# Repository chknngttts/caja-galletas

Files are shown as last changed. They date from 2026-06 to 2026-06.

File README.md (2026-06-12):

# caja-galletas

> *Caja de ruido en proceso*
>
> *Todas las versiones de KiCad están en sus carpetas propias*

-------------------

- ### Ideas y specs

> *La idea es tener esta PCB en una caja de galletas*
> 
> *La placa en sí ya tiene efectos integrados como reverb y un Muff Fuzz*
> 
> *La caja se conecta a un parlante o pc con Jack 3.5mm*
> 
> *Y como alimentación también cuenta con un Jack 3.5mm*
> 

  - Dentro de la caja hay:
    - Regulador de voltaje **``(9V -----> 5V)``**
      - VBUS
    - Reverb **``(PT2399)``**
      - *Switch para tener feedback*
    - Pre-Amp / Amp **``(TL072)``**
    - Muff Fuzz **``(2N5088)``**

-  ## **v2**

- ### esquematico v2

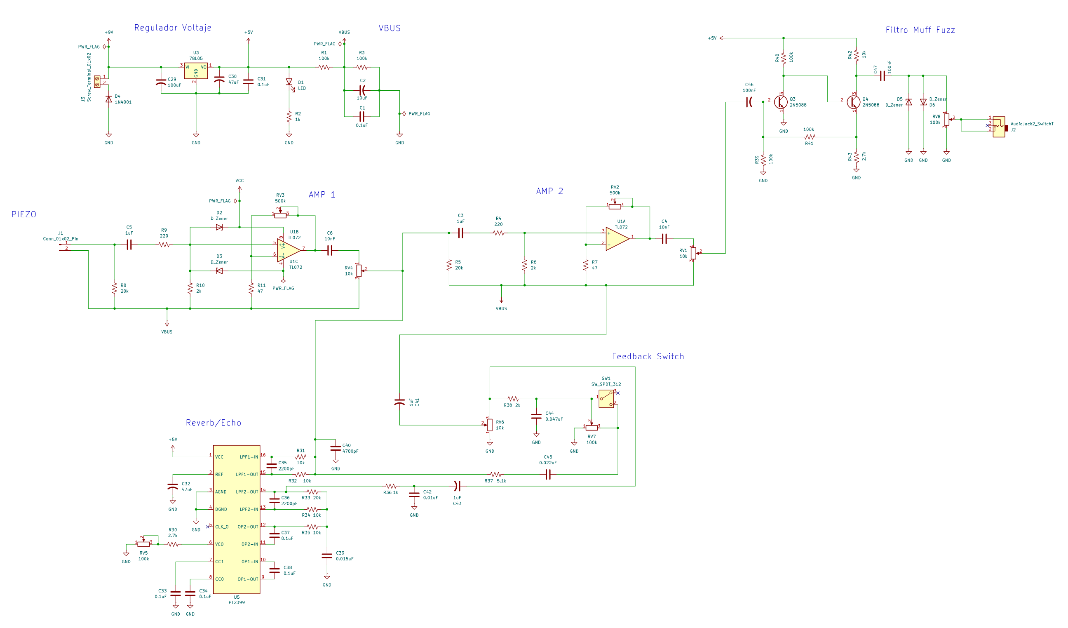
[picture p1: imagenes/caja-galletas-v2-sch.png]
v2 esquematico
-  

-  El esqumatico del PT2399 es el "Boy in Well" con un mod de DIY Guitar Pedals:
    - https://youtu.be/9sHnaUfTWug?si=lqVHKw3zSinBoRW7&t=106 (1:46 - 4:46)
    - Muestra que cortando la conexión de un potenciómetro (RV7) con un switch y bajando el valor de una resistencia (R37), permite que la señal no se filtre (y no pierda info) para que llegue de vuelta al PT2399 haciendo repeats infinitos
      - https://www.diyguitarpedals.com.au/shop/boms/Boy%20in%20Well.pdf (Esquematico original sin switch) (Pagina 30)
    - En KiCad al hacer el ERC no me arroja errores
      - Solo 2 avisos de simbolos que modifiqué para hacer más facil el esquematico
      - En la PBC tampoco me muestra errores de conexión
        - Si quiero cambiar el tamaño y orden de la placa
          - Más rectangular y ahorrar espacio
         
-------------------
- Pre-Amp:         
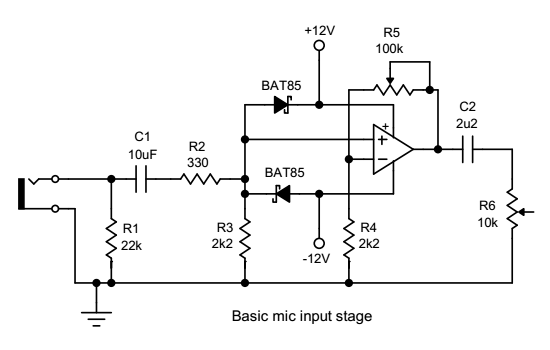
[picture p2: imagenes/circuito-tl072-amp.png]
pre-amp
  - 
  - El Amp que tomé de referencia, es el mismo que el de [maincra](https://github.com/disenoUDP/dis8644-2026-1-procesos-2/tree/main/00-proyecto-02/grupo-01)
    - Con los cambios para hacer más sensible el piezo (R4 y R5)
    - Eso sí, ahora usando ambos OP-Amps

- Muff Fuzz:
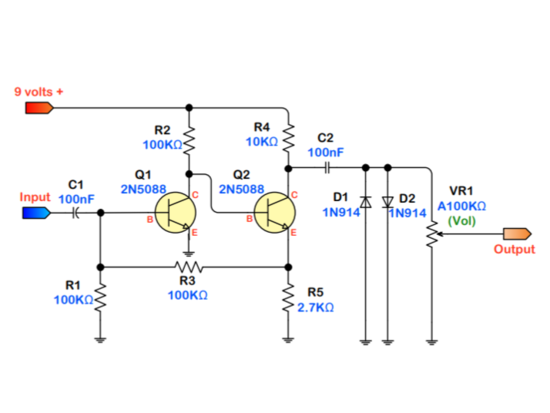
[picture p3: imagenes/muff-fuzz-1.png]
muff-fuzz
  - 
  - El efecto "Muff Fuzz" lo saqué de esta pagina:
    - https://beavisaudio.com/beavisboard/projects/bbp_MuffFuzz.pdf
 
-------------------

- ### pcb v2

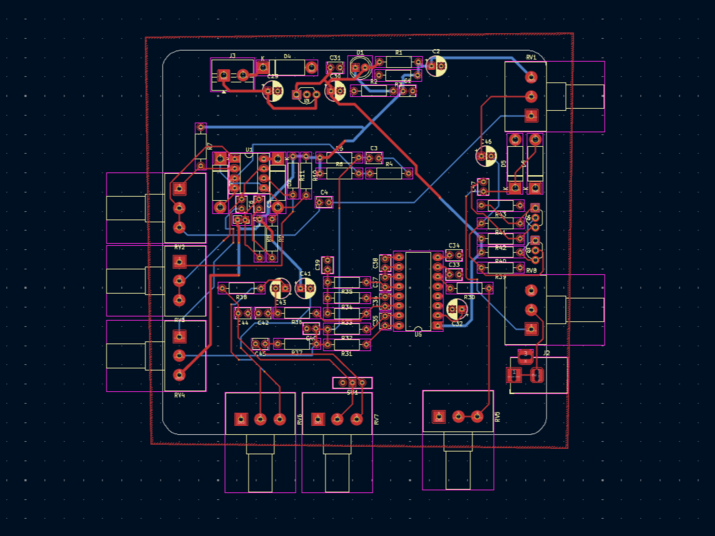
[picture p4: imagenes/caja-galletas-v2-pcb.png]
v2 pcb 2d
- 
  - Tengo que arreglar las vías *(?)*
    - Sin querer use el tamaño predeterminado, no se si eso vaya a ser un problema
  - La huella de los 2N5088 y 78L05 tienen uno externo a la biblioteca de KiCad
    - Los cambié por uno de la biblioteca default en el v3
      - Además de corregir un alivio termico que no nombraban en los errores pero si era preocupante
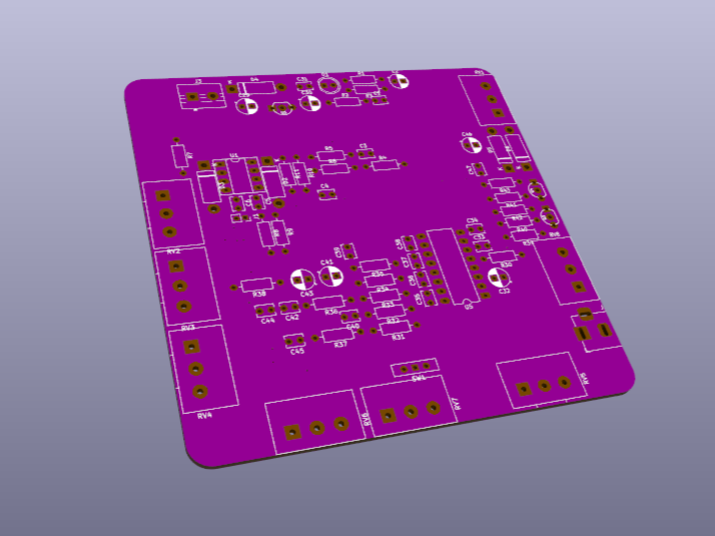
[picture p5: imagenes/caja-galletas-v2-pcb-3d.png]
v2 pcb 3d
- 
  - Hay espacio vacío que me permite re-ordenar los componentes y achicar el tamaño de la PCB
 
-------------------
 
- #### *v3 fueron arreglos minimos de huellas*

-------------------

- ## **v4**

- ### esquematico v4
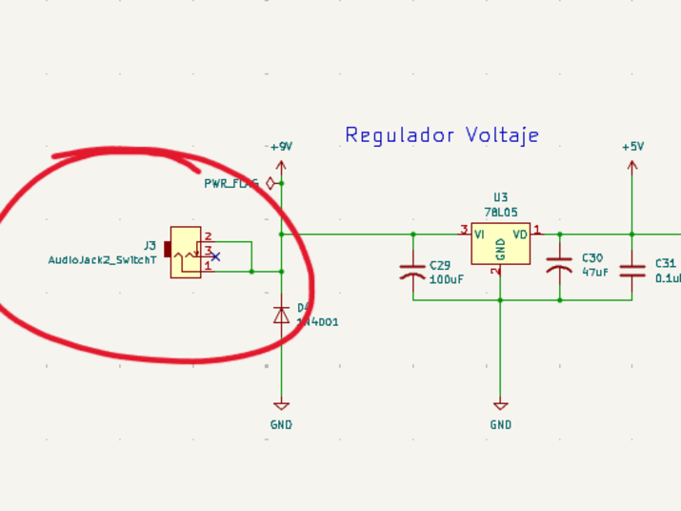
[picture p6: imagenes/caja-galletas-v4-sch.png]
v4 esquematico
  - 
    - igual que v2 pero con Jack 3.5mm a cambio del Terminal Block
 
-------------------
 
- ### pcb v4

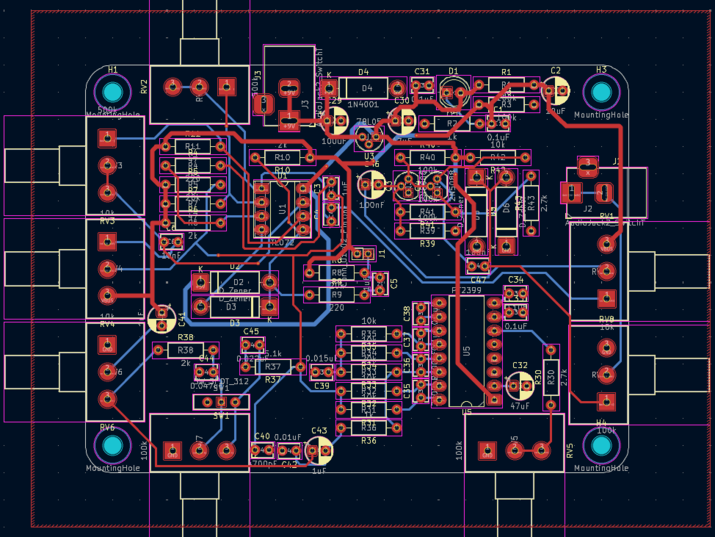
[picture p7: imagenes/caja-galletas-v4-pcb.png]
v4 pcb 2d
- 
  - Cambié las vías al tamaño que nos recomendaros en taller
    - Optimicé la posición de los componentes para usar el espacio vacío
  - Añadí Mounting Holes M3
  - Al ver los errores solo mostraba problemas de la serigrafía
    - Nada con alivios termicos
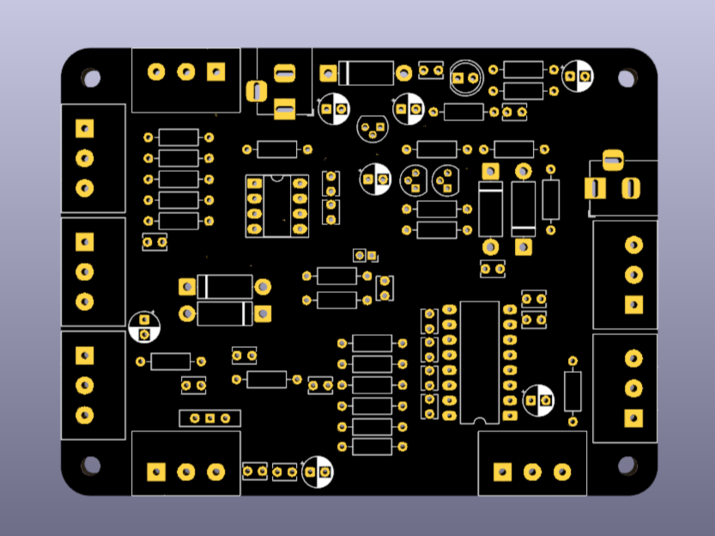
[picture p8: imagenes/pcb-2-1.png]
- 
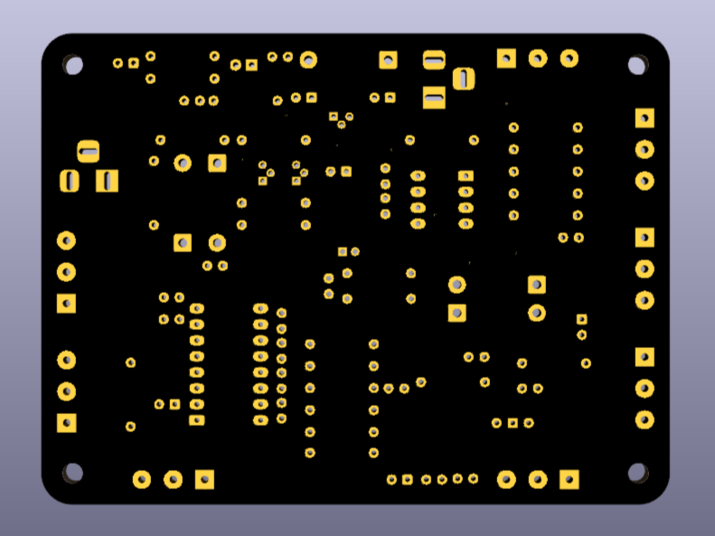
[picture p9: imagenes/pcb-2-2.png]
- 
  - Prefiero el color negro a rosado/morado

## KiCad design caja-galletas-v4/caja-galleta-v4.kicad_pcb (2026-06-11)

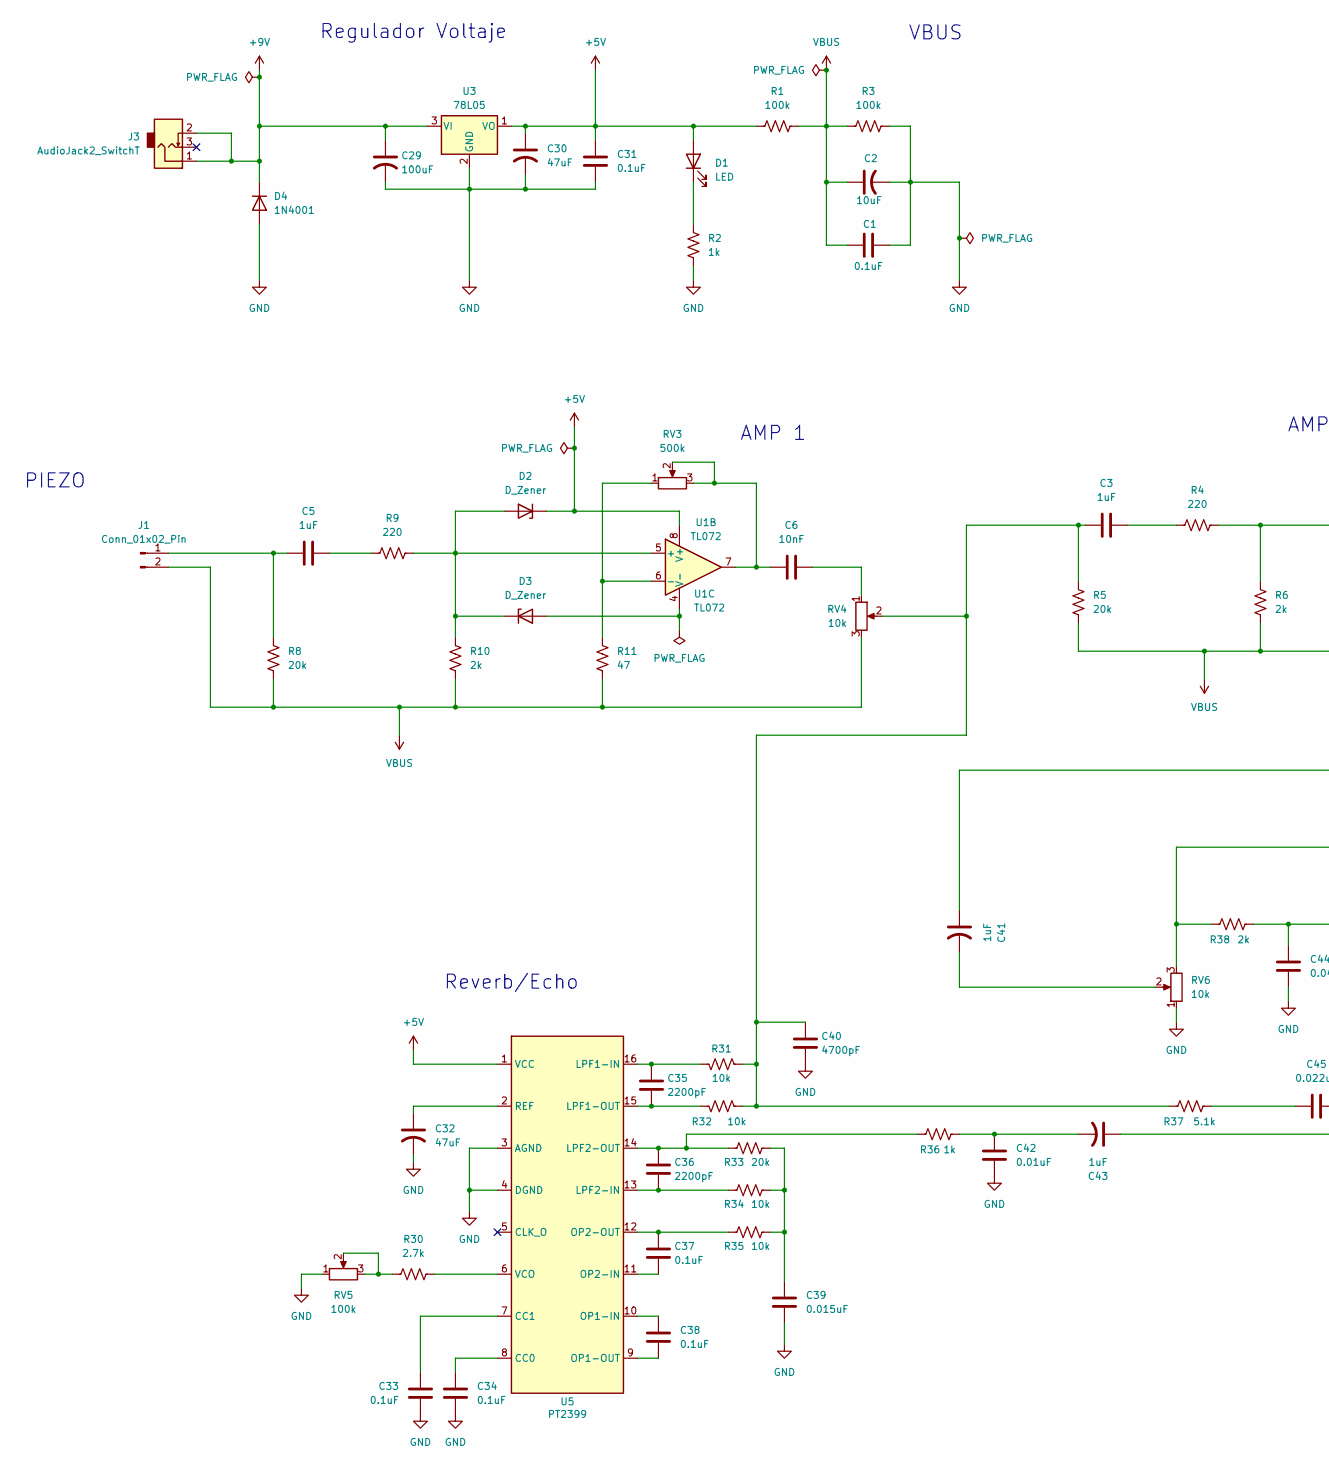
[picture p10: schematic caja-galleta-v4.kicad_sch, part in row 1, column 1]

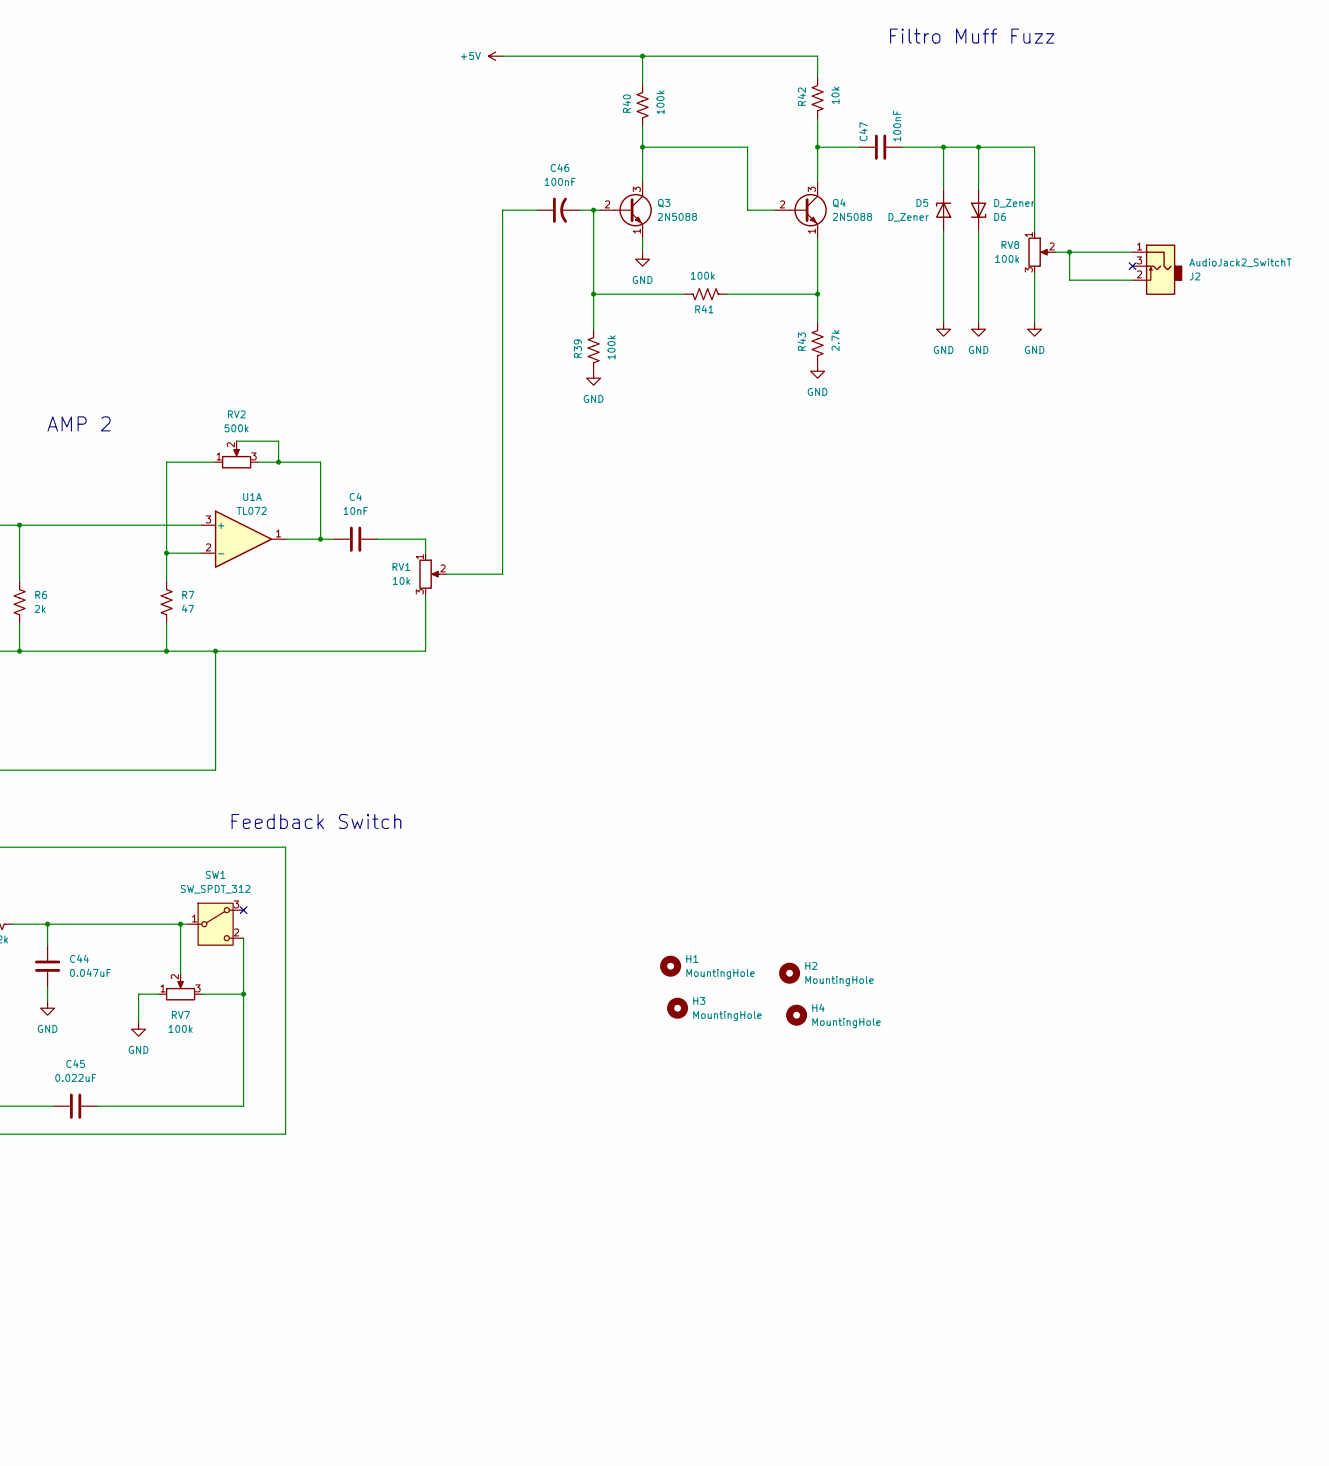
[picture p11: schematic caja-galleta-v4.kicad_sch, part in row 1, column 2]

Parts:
C1, C31, C33, C34, C37, C38: 0.1uF; C_Disc_D3.8mm_W2.6mm_P2.50mm
C2: 10uF; CP_Radial_D5.0mm_P2.50mm
C3, C5: 1uF; C_Disc_D3.8mm_W2.6mm_P2.50mm
C4, C6: 10nF; C_Disc_D3.8mm_W2.6mm_P2.50mm
C29: 100uF; CP_Radial_D5.0mm_P2.50mm
C30, C32: 47uF; CP_Radial_D5.0mm_P2.50mm
C35, C36: 2200pF; C_Disc_D3.8mm_W2.6mm_P2.50mm
C39: 0.015uF; C_Disc_D3.8mm_W2.6mm_P2.50mm
C40: 4700pF; C_Disc_D3.8mm_W2.6mm_P2.50mm
C41, C43: 1uF; CP_Radial_D5.0mm_P2.50mm
C42: 0.01uF; C_Disc_D3.8mm_W2.6mm_P2.50mm
C44: 0.047uF; C_Disc_D3.8mm_W2.6mm_P2.50mm
C45: 0.022uF; C_Disc_D3.8mm_W2.6mm_P2.50mm
C46: 100nF; CP_Radial_D5.0mm_P2.50mm
C47: 100nF; C_Disc_D3.8mm_W2.6mm_P2.50mm
D1: LED; LED_D5.0mm
D2, D3, D5, D6: D_Zener; D_5W_P12.70mm_Horizontal
D4: 1N4001; D_5W_P12.70mm_Horizontal
H1, H2, H3, H4: MountingHole; MountingHole_3.2mm_M3
J1: Conn_01x02_Pin; PinSocket_1x02_P2.00mm_Vertical
J2, J3: AudioJack2_SwitchT; BarrelJack_Horizontal
Q3, Q4: 2N5088; TO-92
R1, R3, R39, R40, R41: 100k; R_Axial_DIN0207_L6.3mm_D2.5mm_P10.16mm_Horizontal
R2, R36: 1k; R_Axial_DIN0207_L6.3mm_D2.5mm_P10.16mm_Horizontal
R4, R9: 220; R_Axial_DIN0207_L6.3mm_D2.5mm_P10.16mm_Horizontal
R5, R8, R33: 20k; R_Axial_DIN0207_L6.3mm_D2.5mm_P10.16mm_Horizontal
R6, R10, R38: 2k; R_Axial_DIN0207_L6.3mm_D2.5mm_P10.16mm_Horizontal
R7, R11: 47; R_Axial_DIN0207_L6.3mm_D2.5mm_P10.16mm_Horizontal
R30, R43: 2.7k; R_Axial_DIN0207_L6.3mm_D2.5mm_P10.16mm_Horizontal
R31, R32, R34, R35, R42: 10k; R_Axial_DIN0207_L6.3mm_D2.5mm_P10.16mm_Horizontal
R37: 5.1k; R_Axial_DIN0207_L6.3mm_D2.5mm_P10.16mm_Horizontal
RV1, RV4, RV6: 10k; Potentiometer_Alps_RK163_Single_Horizontal
RV2, RV3: 500k; Potentiometer_Alps_RK163_Single_Horizontal
RV5, RV7, RV8: 100k; Potentiometer_Alps_RK163_Single_Horizontal
SW1: SW_SPDT_312; SW_Slide-03_Wuerth-WS-SLTV_10x2.5x6.4_P2.54mm
U1: TL072; DIP-8_W7.62mm_Socket_LongPads
U3: 78L05; TO-92
U5: PT2399; DIP-16_W10.16mm_LongPads

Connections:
+5V: C30.1, C31.1, D1.2 (A), D2.1 (K), R1.1, R40.2, R42.2, U1.8 (V+), U3.1 (VO), U5.1 (VCC)
+9V: C29.1, D4.1 (K), J3.1, J3.2, U3.3 (VI)
GND: C1.2, C2.2, C29.2, C30.2, C31.2, C32.2, C33.2, C34.2, C39.2, C40.2, C42.2, C44.1, D4.2 (A), D5.2 (A), D6.1 (K), Q3.1 (E), R2.1, R3.2, R39.1, R43.1, RV5.1, RV6.1, RV7.1, RV8.3, U3.2 (GND), U5.3 (AGND), U5.4 (DGND)
unnamed: C3.1, C40.1, R5.2, R31.2, R32.2, R37.1, RV4.2
unnamed: C3.2, R4.2
unnamed: C4.1, RV2.2, RV2.3, U1.1
unnamed: C4.2, RV1.1
unnamed: C5.2, R9.2
unnamed: C6.1, RV3.2, RV3.3, U1.7
unnamed: C6.2, RV4.1
unnamed: C39.1, R33.2, R34.2, R35.2
unnamed: C41.2, RV6.2
unnamed: C42.1, C43.2, R36.2
unnamed: C43.1, R38.1, RV6.3
unnamed: C45.1, R37.2
unnamed: C46.1, RV1.2
unnamed: D1.1 (K), R2.2
unnamed: D2.2 (A), D3.1 (K), R9.1, R10.2, U1.5 (+)
unnamed: D3.2 (A), U1.4 (V-)
unnamed: C47.1, D5.1 (K), D6.2 (A), RV8.1
unnamed: C5.1, J1.1, R8.2
unnamed: J2.1, J2.2, RV8.2
unnamed: C46.2, Q3.2 (B), R39.2, R41.2
unnamed: Q3.3 (C), Q4.2 (B), R40.1
unnamed: C47.2, Q4.3 (C), R42.1
unnamed: Q4.1 (E), R41.1, R43.2
unnamed: R30.1, RV5.2, RV5.3
unnamed: C44.2, R38.2, RV7.2, SW1.1 (B)
unnamed: C45.2, RV7.3, SW1.2 (C)
unnamed: R4.1, R6.2, U1.3 (+)
unnamed: R7.2, RV2.1, U1.2 (-)
unnamed: R11.2, RV3.1, U1.6 (-)
unnamed: C34.1, U5.8 (CC0)
unnamed: C33.1, U5.7 (CC1)
unnamed: C35.1, R31.1, U5.16 (LPF1-IN)
unnamed: C35.2, R32.1, U5.15 (LPF1-OUT)
unnamed: C36.2, R34.1, U5.13 (LPF2-IN)
unnamed: C36.1, R33.1, R36.1, U5.14 (LPF2-OUT)
unnamed: C38.1, U5.10 (OP1-IN)
unnamed: C38.2, U5.9 (OP1-OUT)
unnamed: C37.2, U5.11 (OP2-IN)
unnamed: C37.1, R35.1, U5.12 (OP2-OUT)
unnamed: C32.1, U5.2 (REF)
unnamed: R30.2, U5.6 (VCO)
VBUS: C1.1, C2.1, C41.1, J1.2, R1.2, R3.1, R5.1, R6.1, R7.1, R8.1, R10.1, R11.1, RV1.3, RV4.3

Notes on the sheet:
AMP 1
Regulador Voltaje
Filtro Muff Fuzz
Feedback Switch
Reverb/Echo
AMP 2
PIEZO
VBUS

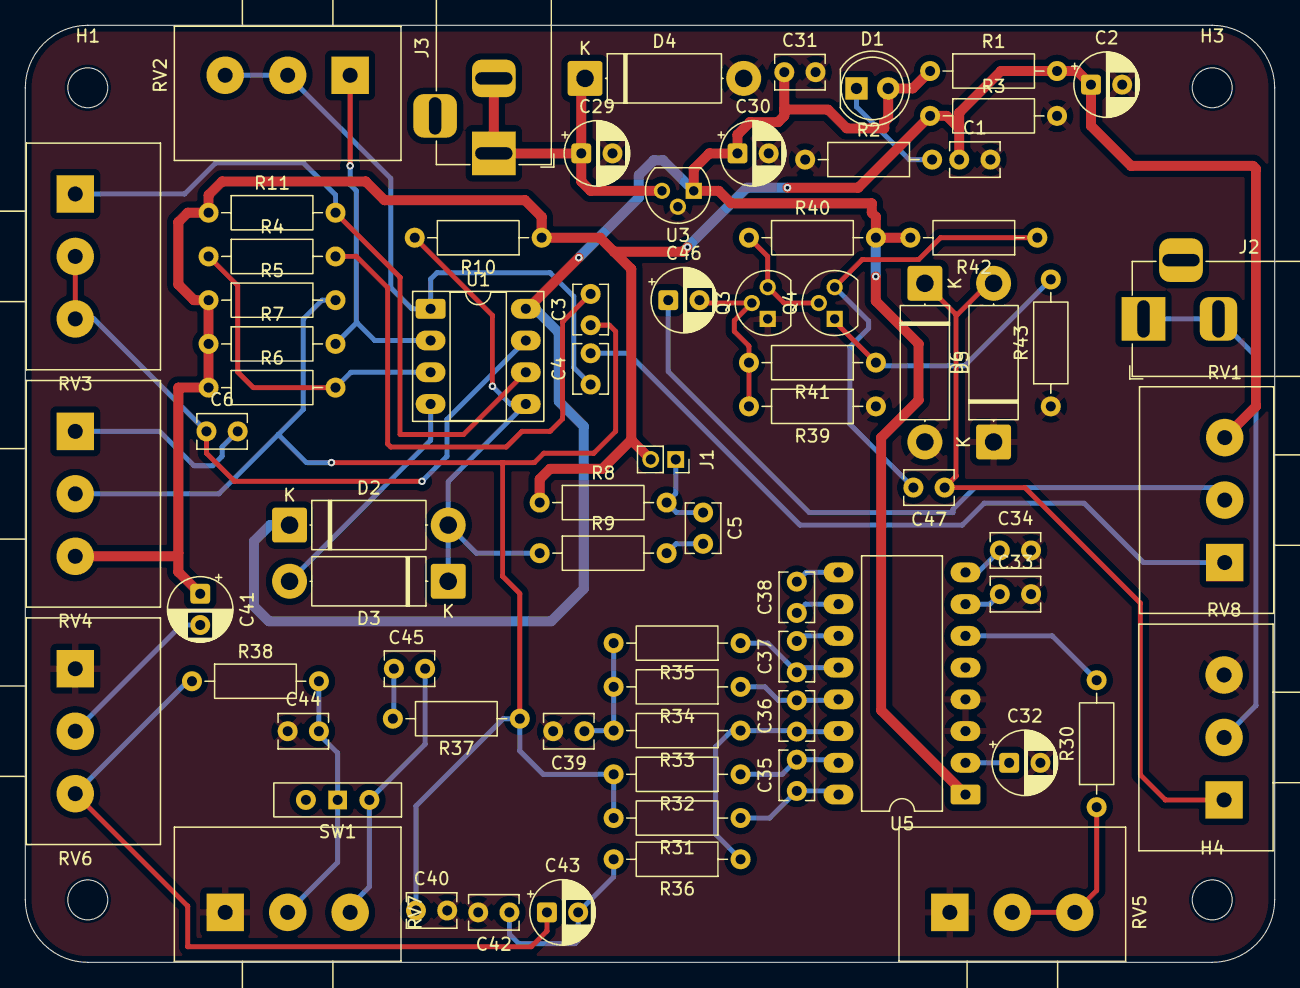
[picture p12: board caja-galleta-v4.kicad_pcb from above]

Board: 2 copper layers, 100.0 x 75.0 mm, 77 parts (0 on the bottom side), 45 nets.
